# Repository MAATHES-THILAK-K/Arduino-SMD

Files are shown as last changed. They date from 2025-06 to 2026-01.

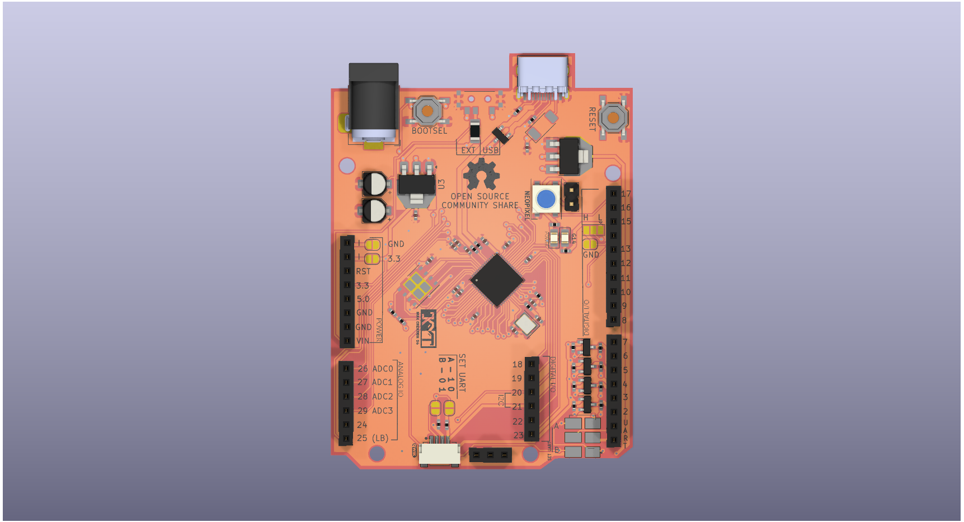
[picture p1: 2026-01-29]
OPENSOURCE_REMAKE/IMAGES/FRONT.png

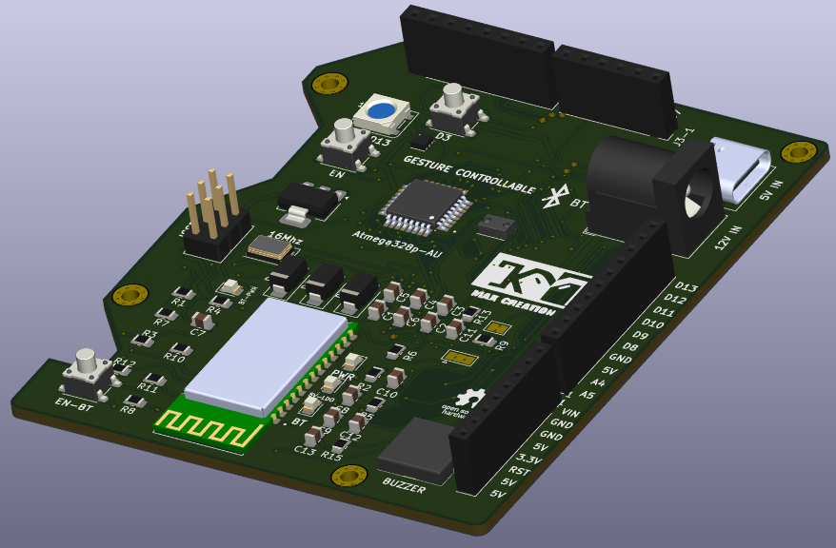
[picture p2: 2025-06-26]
ISOMETRIC_VIEW.png

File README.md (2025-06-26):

# Arduino-SMD

GrabCAD Link: [https://grabcad.com/library/arduino-smd-1](https://grabcad.com/library/arduino-smd-1)

This project is a compact, stylish, Arduino-compatible development board based on the **ATmega328P-AU** (TQFP). It includes several integrated peripherals making it ideal for wearable or IoT projects.

---

## 📦 Components

| Component | Description |
| --- | --- |
| **ATmega328P-AU** | 8-bit microcontroller (TQFP) |
| **AMS1117-3.3V LDO** | 5V to 3.3V regulator for APDS9960 & HC-05 |
| **TLV76750** | 12V to 5V LDO |
| **WS2812B** | RGB LED (Smart addressable) |
| **APDS-9960** | Gesture sensor (I2C) |
| **HC-05** | Bluetooth module |
| **Tactile Switch** | User input |
| **Active Buzzer** | Sound feedback |
| **USB-C (Power-only)** | 5V input only (no data lines) |
| **12V Barrel Jack** | Additional power input |
| **ICSP Header (2x3)** | For firmware flashing |
| **GPIO Headers** | Female headers for D0-D13, A0-A5 |
| **Various SMD Resistors & Capacitors** | For pull-ups, bypassing, filtering |

---

## ⚠️ Warning

> **The DRC (Design Rule Check) in KiCad was not fully resolved during initial layout. There may be trace width, clearance, or connectivity issues. Please verify the layout manually or run a complete DRC pass before fabrication.**

---

## 📁 Folder Info

* **Gerber/** → Ready-to-export Gerber files for fabrication
* **KiCad\_Project/** → All source files for the schematic & layout
* **images/** → (Optional) Screenshots, 3D renders of the board
* **LICENSE** → MIT License for reuse
* **.gitignore** → Standard for KiCad projects

---

## 🛠️ To-Do

* [ ] Fix all DRC errors
* [ ] Add 3D renders
* [ ] Test hardware once fabricated

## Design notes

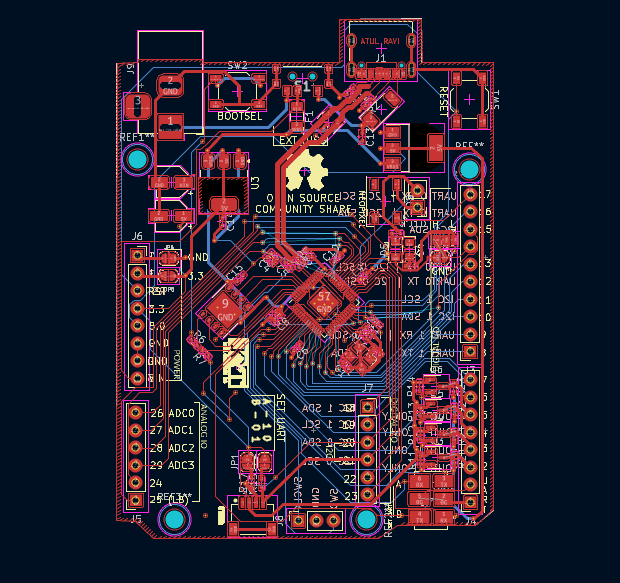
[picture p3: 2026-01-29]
OPENSOURCE_REMAKE/IMAGES/Screenshot from 2026-01-29 20-04-23.png

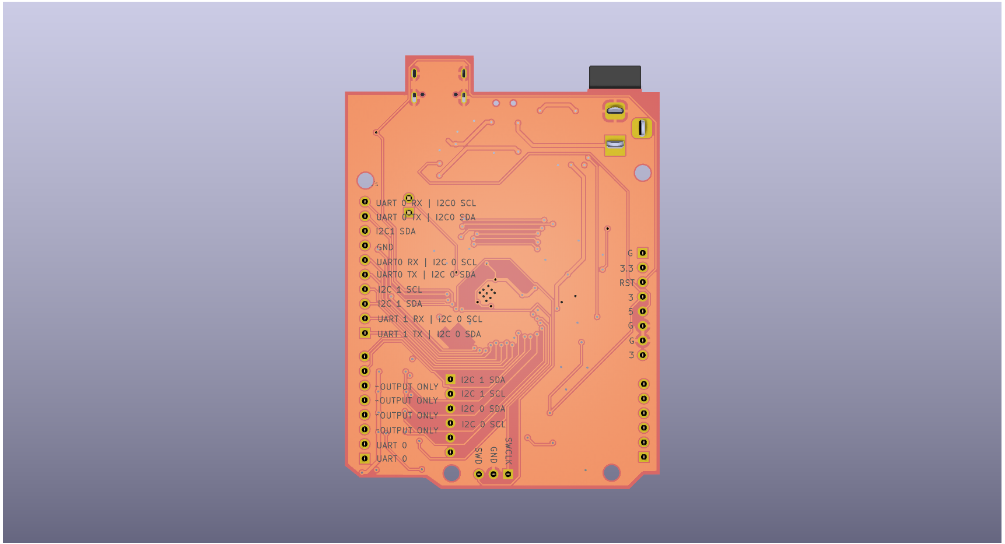
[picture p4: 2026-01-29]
OPENSOURCE_REMAKE/IMAGES/BACK.png

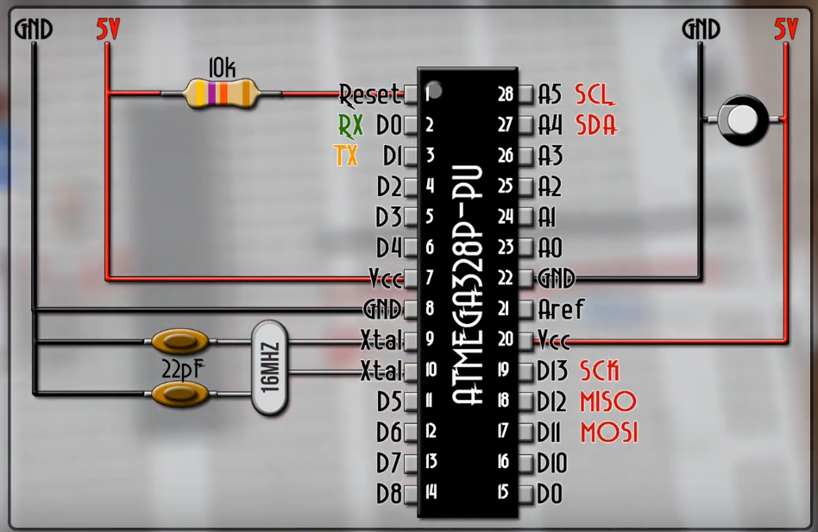
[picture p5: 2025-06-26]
BARE_MINIMUM_CONFIGURATION.png

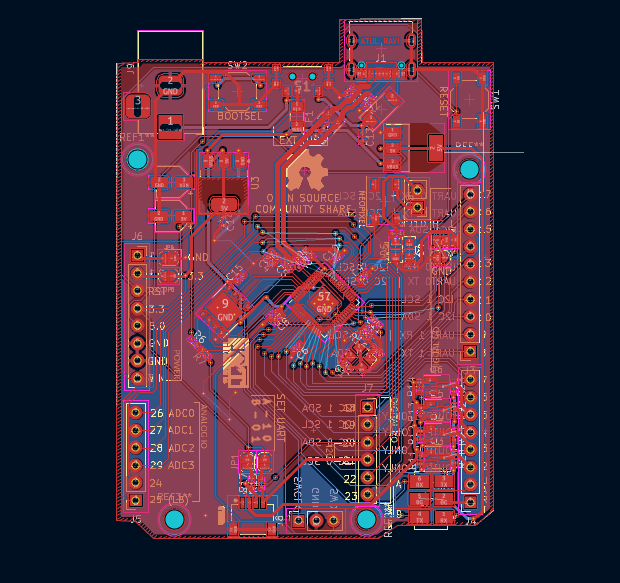
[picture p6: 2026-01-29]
OPENSOURCE_REMAKE/IMAGES/Screenshot from 2026-01-29 20-04-18.png

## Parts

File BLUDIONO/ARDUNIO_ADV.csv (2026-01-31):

Reference | Qty | Value | DNP | Exclude from BOM | Exclude from Board | Footprint | Datasheet
BZ1 | 1 | Buzzer |  |  |  | PKMCS0909E4000-R1:SPKR_PKMCS0909E4000-R1 | ~
C1,C2,C13 | 3 | 100nf |  |  |  | Capacitor_SMD:C_0805_2012Metric | ~
C3,C4 | 2 | 22pf |  |  |  | Capacitor_SMD:C_0805_2012Metric | ~
C5 | 1 | 1uf |  |  |  | Capacitor_SMD:C_0805_2012Metric | ~
C6 | 1 | 2.2uf |  |  |  | Capacitor_SMD:C_0805_2012Metric | ~
C7,C8 | 2 | 10uf |  |  |  | Capacitor_SMD:C_0805_2012Metric | ~
C9 | 1 | 0.1uf |  |  |  | Capacitor_SMD:C_0805_2012Metric | ~
C10 | 1 | 1.0uf |  |  |  | Capacitor_SMD:C_0805_2012Metric | ~
C11 | 1 | 100uf |  |  |  | Capacitor_SMD:C_0805_2012Metric | ~
C12 | 1 | 1.0fu |  |  |  | Capacitor_SMD:C_0805_2012Metric | ~
D1,D3,D5 | 3 | SS14 |  |  |  | Diode_SMD:D_SMA | https://www.vishay.com/docs/88746/ss12.pdf
D2,D6,D7,D8 | 4 | LED |  |  |  | LED_SMD:LED_0805_2012Metric | ~
D4 | 1 | WS2812B |  |  |  | LED_SMD:LED_WS2812B_PLCC4_5.0x5.0mm_P3.2mm | https://cdn-shop.adafruit.com/datasheets/WS2812B.pdf
H1,H2,H3,H4 | 4 | MountingHole |  | Excluded from BOM |  | MountingHole:MountingHole_2.2mm_M2_Pad_Via | ~
J1 | 1 | ICSP |  |  |  | Connector_PinHeader_2.54mm:PinHeader_2x03_P2.54mm_Vertical | ~
J1-1 | 1 | Conn_01x10_Pin |  |  |  | Connector_PinSocket_2.54mm:PinSocket_1x10_P2.54mm_Vertical | ~
J2 | 1 | USB_C_Receptacle_PowerOnly_6P |  |  |  | Connector_USB:USB_C_Receptacle_HRO_TYPE-C-31-M-12 | https://www.usb.org/sites/default/files/documents/usb_type-c.zip
J2-1,J4-1 | 2 | Conn_01x08_Pin |  |  |  | Connector_PinSocket_2.54mm:PinSocket_1x08_P2.54mm_Vertical | ~
J3 | 1 | Barrel_Jack |  |  |  | Connector_BarrelJack:BarrelJack_CUI_PJ-102AH_Horizontal | ~
J3-1 | 1 | Conn_01x06_Pin |  |  |  | Connector_PinSocket_2.54mm:PinSocket_1x06_P2.54mm_Vertical | ~
JP1 | 1 | SolderJumper_3_Bridged123 |  | Excluded from BOM |  | Jumper:SolderJumper-3_P1.3mm_Bridged2Bar123_Pad1.0x1.5mm | ~
JP2 | 1 | SolderJumper_2_Bridged |  | Excluded from BOM |  | Jumper:SolderJumper-2_P1.3mm_Bridged_Pad1.0x1.5mm | ~
R1,R7,R11 | 3 | 10k |  |  |  | Resistor_SMD:R_0805_2012Metric | ~
R2,R12 | 2 | 1k |  |  |  | Resistor_SMD:R_0805_2012Metric | ~
R3 | 1 | 330 |  |  |  | Resistor_SMD:R_0805_2012Metric | ~
R4 | 1 | 2.2k |  |  |  | Resistor_SMD:R_0805_2012Metric | ~
R5,R6 | 2 | 4.7k |  |  |  | Resistor_SMD:R_0805_2012Metric | ~
R8 | 1 | 100 |  |  |  | Resistor_SMD:R_0805_2012Metric | ~
R9 | 1 | DNP |  |  |  | Resistor_SMD:R_0805_2012Metric | ~
R10 | 1 | 2k |  |  |  | Resistor_SMD:R_0805_2012Metric | ~
R13,R14 | 2 | 5.1k |  |  |  | Resistor_SMD:R_0805_2012Metric | ~
R15 | 1 | 1M |  |  |  | Resistor_SMD:R_0805_2012Metric | ~
SW2,SW3,SW4 | 3 | SW_DPST_x2 |  |  |  | Button_Switch_SMD:SW_SPST_PTS647_Sx50 | ~
U1 | 1 | ATMEGA328P-AU |  |  |  | ATMEGA328P_AU:QFP80P900X900X120-32N
U2 | 1 | TLV76750DRVx |  |  |  | Package_SON:WSON-6-1EP_2x2mm_P0.65mm_EP1x1.6mm_ThermalVias | www.ti.com/lit/gpn/TLV767
U3 | 1 | AMS1117-3.3 |  |  |  | Package_TO_SOT_SMD:SOT-223-3_TabPin2 | http://www.advanced-monolithic.com/pdf/ds1117.pdf
U4 | 1 | APDS-9960 |  |  |  | Sensor:Avago_APDS-9960 | https://docs.broadcom.com/doc/AV02-4191EN
U5 | 1 | HC-05 |  |  |  | HC-05:XCVR_HC-05
Y1 | 1 | Crystal |  |  |  | Crystal:Crystal_SMD_5032-2Pin_5.0x3.2mm | ~

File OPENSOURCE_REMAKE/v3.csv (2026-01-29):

Reference | Qty | Value | DNP | Exclude from BOM | Exclude from Board | Footprint | Datasheet
C1,C2 | 2 | 27p |  |  |  | Capacitor_SMD:C_0402_1005Metric_Pad0.74x0.62mm_HandSolder | ~
C3,C4,C6,C7,C8,C9,C10,C11,C15 | 9 | 100n |  |  |  | Capacitor_SMD:C_0402_1005Metric_Pad0.74x0.62mm_HandSolder | ~
C5,C12 | 2 | 1u |  |  |  | Capacitor_SMD:C_0402_1005Metric_Pad0.74x0.62mm_HandSolder | ~
C13 | 1 | 10u |  |  |  | Capacitor_SMD:C_0402_1005Metric_Pad0.74x0.62mm_HandSolder | ~
C14 | 1 | 22pF |  |  |  | Capacitor_SMD:C_0402_1005Metric_Pad0.74x0.62mm_HandSolder | ~
C16,C17 | 2 | 10uF |  |  |  | Capacitor_SMD:CP_Elec_4x5.4 | ~
D1 | 1 | D_Schottky |  |  |  | Diode_SMD:D_SOD-128 | ~
D2 | 1 | WS2812B |  |  |  | LED_SMD:LED_WS2812B_PLCC4_5.0x5.0mm_P3.2mm | https://cdn-shop.adafruit.com/datasheets/WS2812B.pdf
D3 | 1 | D_TVS_Dual_AAC |  |  |  | Package_TO_SOT_SMD:SOT-23 | ~
D4,D5 | 2 | LED |  |  |  | LED_SMD:LED_0805_2012Metric_Pad1.15x1.40mm_HandSolder | ~
F1 | 1 | Fuse |  |  |  | Fuse:Fuse_1206_3216Metric_Pad1.42x1.75mm_HandSolder | ~
J1 | 1 | USB_C_Receptacle_USB2.0 |  |  |  | Connector_USB:USB_C_Receptacle_G-Switch_GT-USB-7010ASV | https://www.usb.org/sites/default/files/documents/usb_type-c.zip
J2 | 1 | SM04B-SRSS-TB_LF__SN_ |  |  |  | SPARKFUN-QWIIC:JST_SM04B-SRSS-TB_LF__SN_
J3 | 1 | Conn_01x10_Socket |  |  |  | Connector_PinSocket_2.54mm:PinSocket_1x10_P2.54mm_Vertical | ~
J4,J6 | 2 | Conn_01x08_Socket |  |  |  | Connector_PinSocket_2.54mm:PinSocket_1x08_P2.54mm_Vertical | ~
J5 | 1 | Conn_01x06_Pin |  |  |  | Connector_PinSocket_2.54mm:PinSocket_1x06_P2.54mm_Vertical | ~
J7 | 1 | Conn_01x06_Socket |  |  |  | Connector_PinSocket_2.54mm:PinSocket_1x06_P2.54mm_Vertical | ~
J8 | 1 | Conn_01x03_Pin |  |  |  | Connector_PinSocket_2.54mm:PinSocket_1x03_P2.54mm_Vertical | ~
J9 | 1 | Barrel_Jack_Switch |  |  |  | Connector_BarrelJack:BarrelJack_Horizontal | ~
J10 | 1 | Conn_01x02_Pin |  |  |  | Connector_PinHeader_2.54mm:PinHeader_1x02_P2.54mm_Vertical | ~
JP1,JP2,JP7,JP8 | 4 | Jumper_2_Bridged |  |  |  | Jumper:SolderJumper-2_P1.3mm_Open_RoundedPad1.0x1.5mm | ~
JP3 | 1 | Jumper_3_Open |  |  |  | Jumper:SolderJumper-3_P1.3mm_Open_Pad1.0x1.5mm | ~
JP4 | 1 | Jumper_2_Open |  |  |  | Jumper:SolderJumper-2_P1.3mm_Open_RoundedPad1.0x1.5mm | ~
Q3,Q4,Q5,Q6 | 4 | BSS138 |  |  |  | Package_TO_SOT_SMD:SOT-23 | https://www.onsemi.com/pub/Collateral/BSS138-D.PDF
R1,R8 | 2 | 220 |  |  |  | Resistor_SMD:R_0402_1005Metric_Pad0.72x0.64mm_HandSolder | ~
R2,R3,R33 | 3 | 5.1K |  |  |  | Resistor_SMD:R_0402_1005Metric_Pad0.72x0.64mm_HandSolder | ~
R4,R5 | 2 | 27R |  |  |  | Resistor_SMD:R_0402_1005Metric_Pad0.72x0.64mm_HandSolder | ~
R6,R16 | 2 | 1k |  |  |  | Resistor_SMD:R_0402_1005Metric_Pad0.72x0.64mm_HandSolder | ~
R7 | 1 | 10k |  |  |  | Resistor_SMD:R_0402_1005Metric_Pad0.72x0.64mm_HandSolder | ~
R11,R12,R13,R14,R20,R21,R22,R23 | 8 | 10K |  |  |  | Resistor_SMD:R_0402_1005Metric_Pad0.72x0.64mm_HandSolder | ~
R15,R17 | 2 | 2.2K |  |  |  | Resistor_SMD:R_0402_1005Metric_Pad0.72x0.64mm_HandSolder | ~
S1 | 1 | SK-3296S-01-L3 |  |  |  | switchess:SK3296S01L3 | https://datasheet.lcsc.com/szlcsc/XKB-SK-3296S-01-L3_C319019.pdf
SW1 | 1 | TACT SW |  |  |  | Button_Switch_SMD:SW_SPST_TL3342 | PTS526SP20SMTR2 LFS
SW2 | 1 | 4*4*1/5 SMD tact SW |  |  |  | Button_Switch_SMD:SW_SPST_TL3342 | https://www.ktron.in/product/4x4x1-5mm-smd-tactile-switch/
SW3 | 1 | SW_DPDT_x2 |  |  |  | switchess:SW_CL-SB-22A-02T | SMMD
U1 | 1 | RP2040 |  |  |  | Package_DFN_QFN:QFN-56-1EP_7x7mm_P0.4mm_EP3.2x3.2mm | https://datasheets.raspberrypi.com/rp2040/rp2040-datasheet.pdf
U3 | 1 | AMS1117-3.3 |  |  |  | Package_TO_SOT_SMD:SOT-223-3_TabPin2 | http://www.advanced-monolithic.com/pdf/ds1117.pdf
U4 | 1 | AMS1117-5.0 |  |  |  | Package_TO_SOT_SMD:SOT-223-3_TabPin2 | http://www.advanced-monolithic.com/pdf/ds1117.pdf
U5 | 1 | W25Q32JVZP |  |  |  | Package_SON:WSON-8-1EP_6x5mm_P1.27mm_EP3.4x4.3mm | http://www.winbond.com/resource-files/w25q32jv%20revg%2003272018%20plus.pdf
Y1 | 1 | \YSX321SL 12 Mhz |  |  |  | Crystal:Crystal_SMD_3225-4Pin_3.2x2.5mm | https://www.ktron.in/wp-content/uploads/2023/02/YSX321SL-Datasheet.pdf

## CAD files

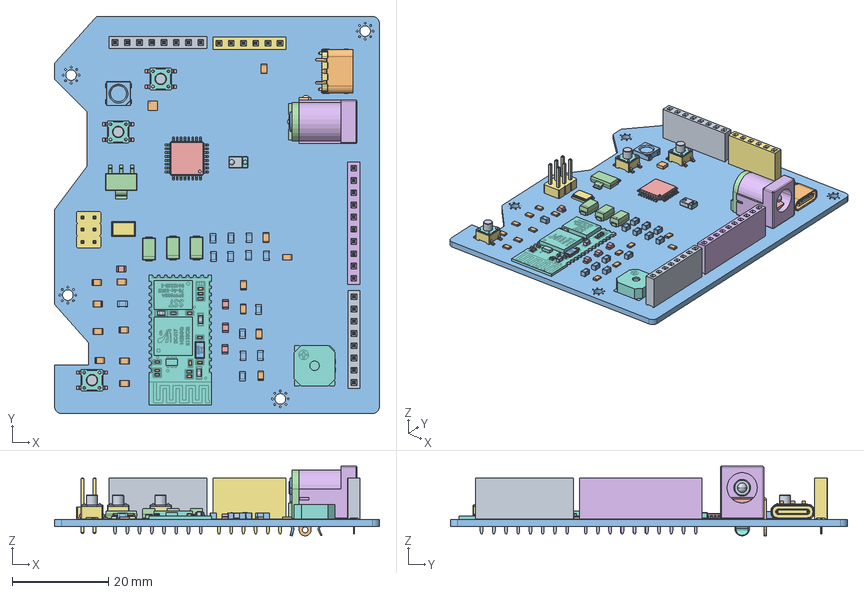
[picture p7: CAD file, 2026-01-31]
BLUDIONO/3D MODEL/ARDUNIO_ADV.step
67.5 x 82.5 x 14.5 mm
R_0805_2012Metric x 15
C_0805_2012Metric x 13
D_SMA x 3
SW_SPST_PTS647Sx50 x 3
USB-C
DCJ200-10-A-K1-K--3DModel-STEP-56544
PinSocket_1x06_P2.54mm_Vertical
smd_buzz
PinSocket_1x08_P2.54mm_Vertical x 2
WSON-6-1EP_2x2mm_P0.65mm_EP1x1.6mm
LED_WS2812B_PLCC4_5.0x5.0mm_P3.2mm
SOT-223
LED_0805_2012Metric x 4
PinSocket_1x10_P2.54mm_Vertical
Crystal_SMD_5032-2Pin_5.0x3.2mm
HC05_06
C0603 x 3
R0402 x 4
C0402 x 9
QSMD7.0x5.0x1.3
ATMEGA328P-AU
PinHeader_2x03_P2.54mm_Vertical
APDS-9960
ARDUNIO_ADV_PCB

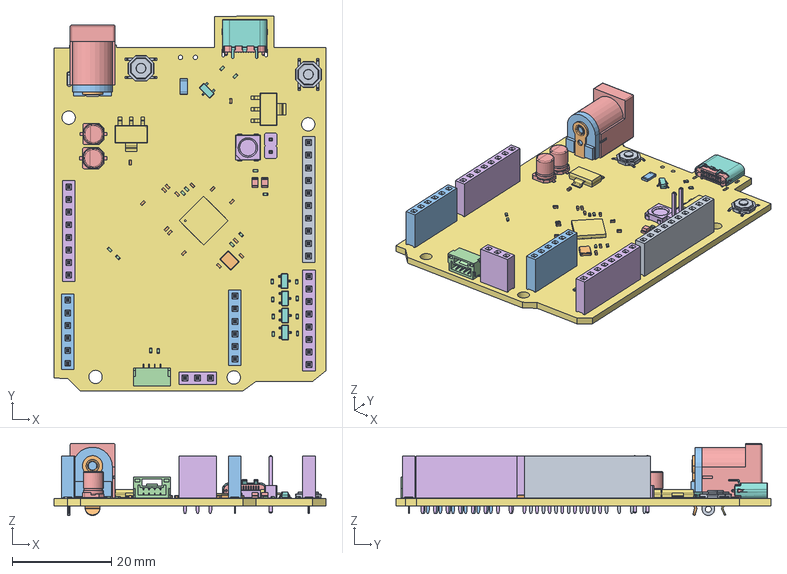
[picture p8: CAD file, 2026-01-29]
OPENSOURCE_REMAKE/3D MODEL/capacitive-midi-pad1.step
54.8 x 75.5 x 14.5 mm
SW_SPST_TL3342 x 2
C_0402_1005Metric x 15
PinSocket_1x06_P2.54mm_Vertical x 2
R_0402_1005Metric x 20
CP_Elec_4x5.4 x 2
PinSocket_1x08_P2.54mm_Vertical x 2
SOT-223 x 2
SOT-23 x 5
PinSocket_1x10_P2.54mm_Vertical
Crystal_SMD_3225-4Pin_3.2x2.5mm
Fuse_1206_3216Metric
JST_GH_SM04B-GHS-TB_1x04-1MP_P1.25mm_Horizontal
LED_0805_2012Metric x 2
PinHeader_1x02_P2.54mm_Vertical
QFN-56-1EP_7x7mm_P0.4mm_EP3.2x3.2mm
USB-C
LED_WS2812B_PLCC4_5.0x5.0mm_P3.2mm
DCJ200-10-A-K1-K--3DModel-STEP-56544
PinSocket_1x03_P2.54mm_Vertical
v3_PCB

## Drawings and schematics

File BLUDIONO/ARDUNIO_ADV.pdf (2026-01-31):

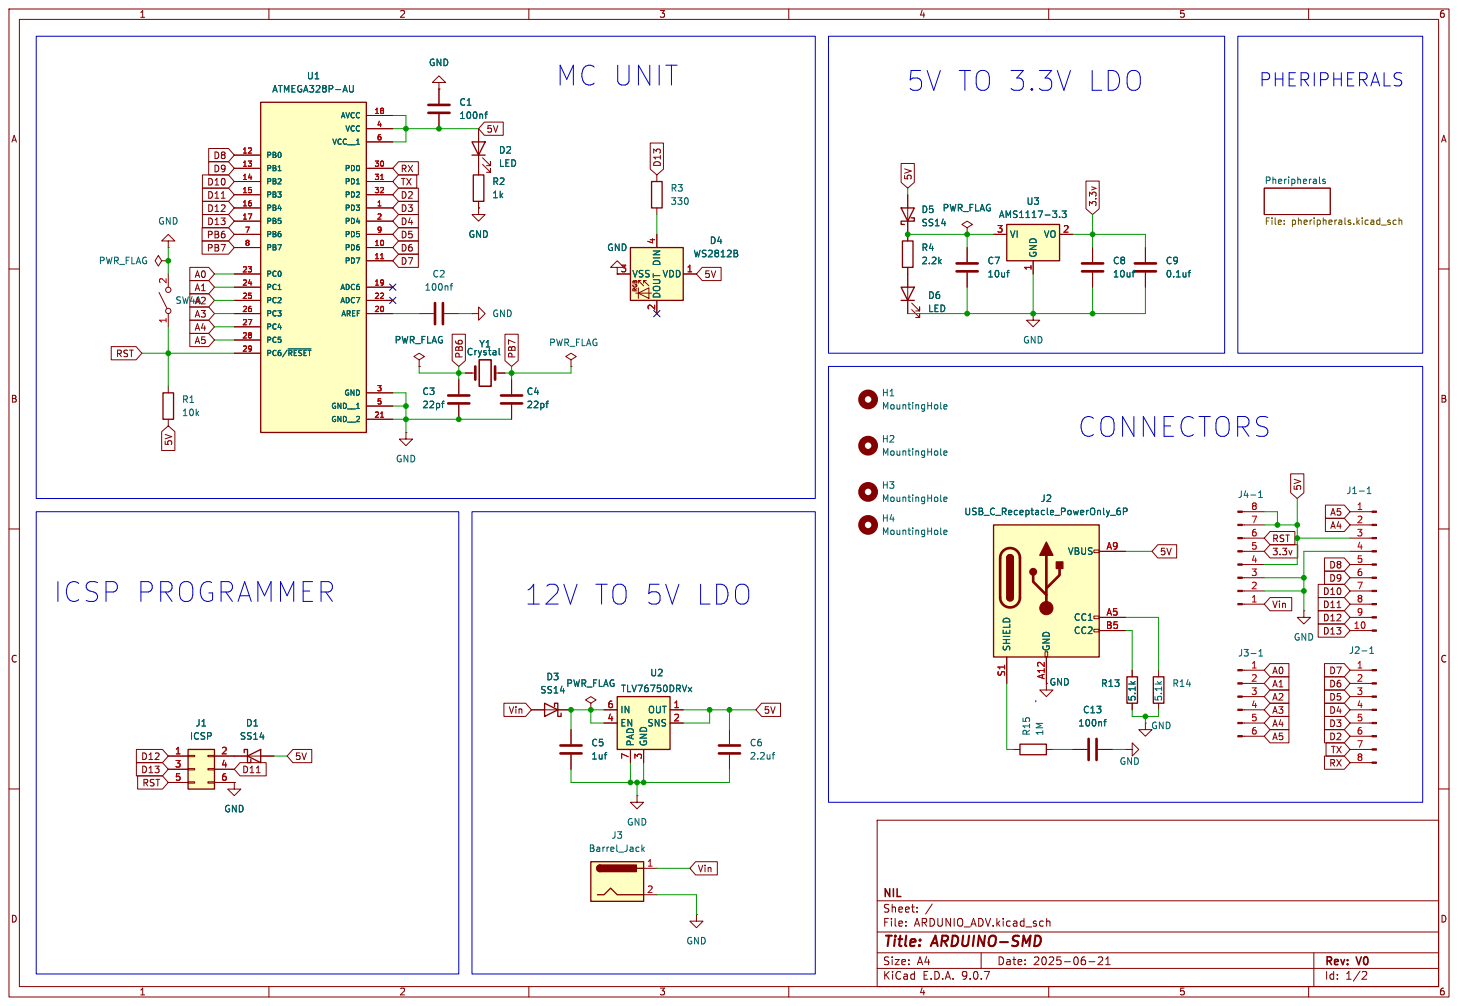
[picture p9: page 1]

Pheripherals File: pheripherals.kicad_sch GND

Id: 1/2 Title: ARDUINO-SMD

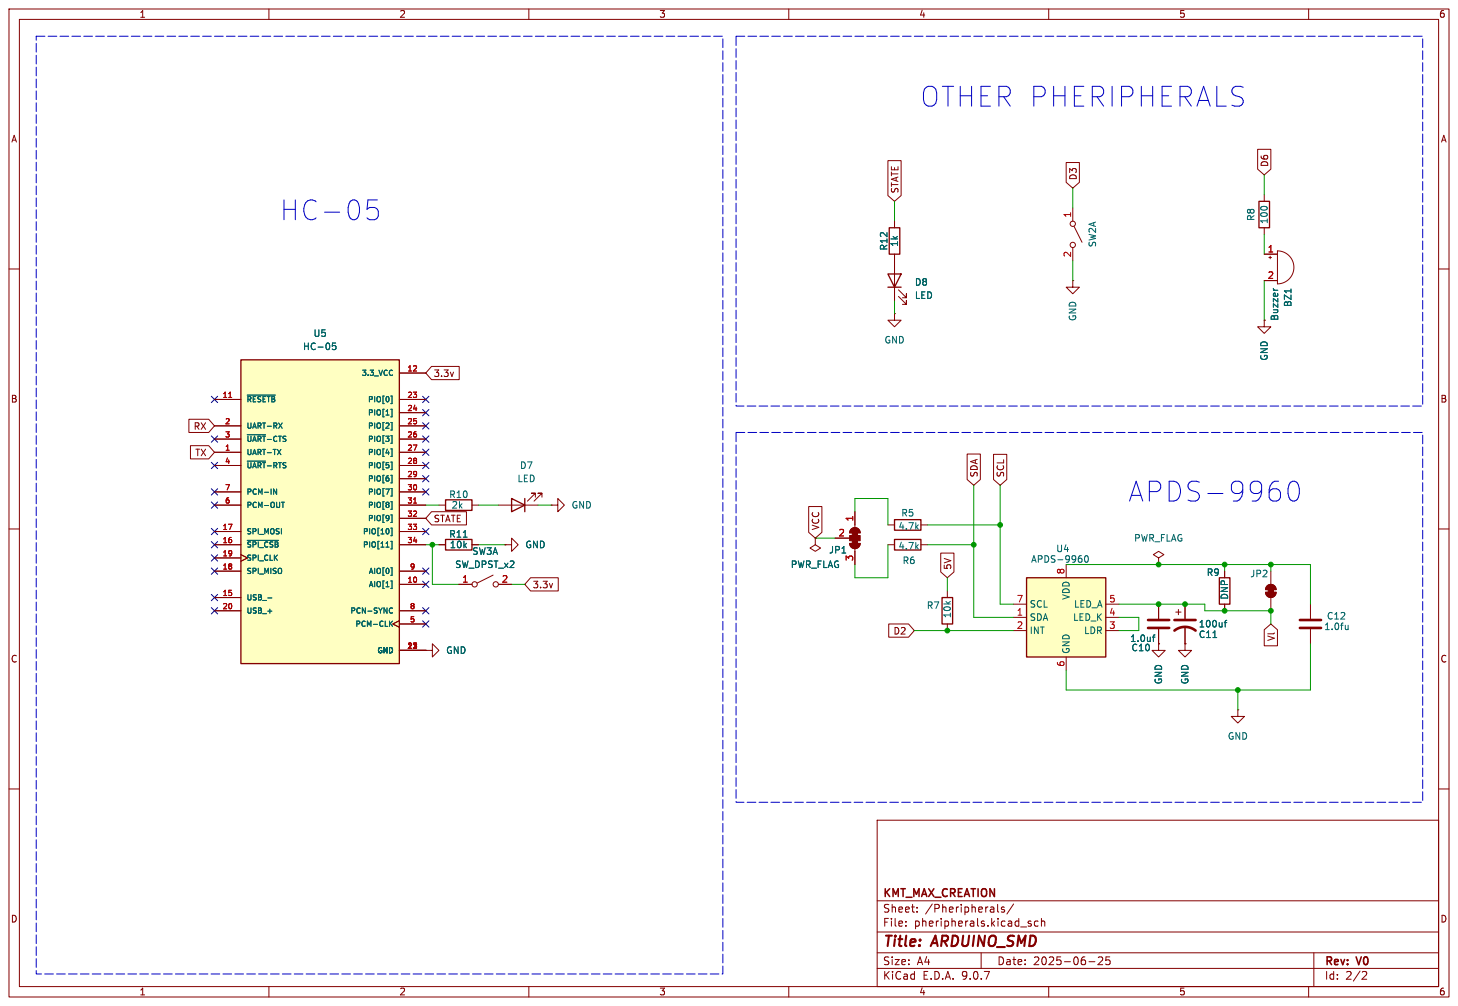
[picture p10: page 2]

KMT_MAX_CREATION
File: pheripherals.kicad_sch Sheet: /Pheripherals/
Id: 2/2 Title: ARDUINO_SMD

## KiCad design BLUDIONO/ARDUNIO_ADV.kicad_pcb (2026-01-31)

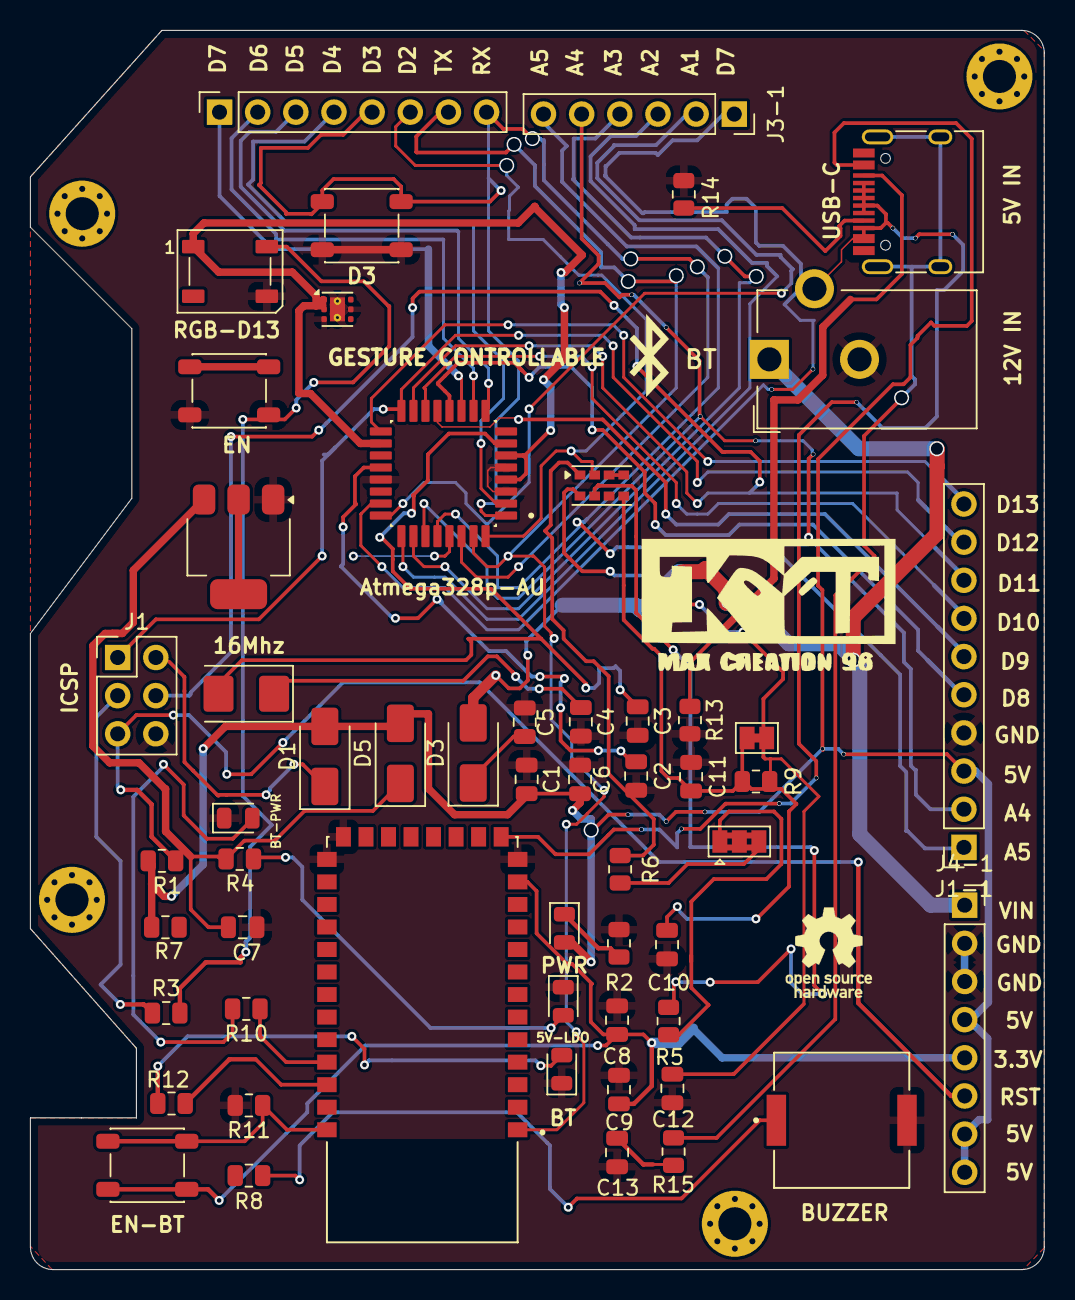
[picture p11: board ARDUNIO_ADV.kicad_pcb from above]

Board: 2 copper layers, 67.5 x 82.5 mm, 59 parts (0 on the bottom side), 51 nets.

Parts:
5V-LDO: LED; LED_0805_2012Metric
12V IN: Barrel_Jack; BarrelJack_CUI_PJ-102AH_Horizontal
16Mhz: Crystal; Crystal_SMD_5032-2Pin_5.0x3.2mm
BT: LED; LED_0805_2012Metric
BT-PWR: LED; LED_0805_2012Metric
BZ1: Buzzer; SPKR_PKMCS0909E4000-R1
C1, C2, C13: 100nf; C_0805_2012Metric
C3, C4: 22pf; C_0805_2012Metric
C5: 1uf; C_0805_2012Metric
C6: 2.2uf; C_0805_2012Metric
C7, C8: 10uf; C_0805_2012Metric
C9: 0.1uf; C_0805_2012Metric
C10: 1.0uf; C_0805_2012Metric
C11: 100uf; C_0805_2012Metric
C12: 1.0fu; C_0805_2012Metric
D1, D3#2, D5: SS14; D_SMA
D3: SW_DPST_x2; SW_SPST_PTS647_Sx50
EN: SW_DPST_x2; SW_SPST_PTS647_Sx50
EN-BT: SW_DPST_x2; SW_SPST_PTS647_Sx50
H1, H2, H3, H4: MountingHole; MountingHole_2.2mm_M2_Pad_Via
J1: ICSP; PinHeader_2x03_P2.54mm_Vertical
J1-1: Conn_01x10_Pin; PinSocket_1x10_P2.54mm_Vertical
J2-1, J4-1: Conn_01x08_Pin; PinSocket_1x08_P2.54mm_Vertical
J3-1: Conn_01x06_Pin; PinSocket_1x06_P2.54mm_Vertical
JP1: SolderJumper_3_Bridged123; SolderJumper-3_P1.3mm_Bridged2Bar123_Pad1.0x1.5mm
JP2: SolderJumper_2_Bridged; SolderJumper-2_P1.3mm_Bridged_Pad1.0x1.5mm
PWR: LED; LED_0805_2012Metric
R1, R7, R11: 10k; R_0805_2012Metric
R2, R12: 1k; R_0805_2012Metric
R3: 330; R_0805_2012Metric
R4: 2.2k; R_0805_2012Metric
R5, R6: 4.7k; R_0805_2012Metric
R8: 100; R_0805_2012Metric
R9: DNP; R_0805_2012Metric
R10: 2k; R_0805_2012Metric
R13, R14: 5.1k; R_0805_2012Metric
R15: 1M; R_0805_2012Metric
RGB-D13: WS2812B; LED_WS2812B_PLCC4_5.0x5.0mm_P3.2mm
U1: ATMEGA328P-AU; QFP80P900X900X120-32N
U2: TLV76750DRVx; WSON-6-1EP_2x2mm_P0.65mm_EP1x1.6mm_ThermalVias
U3: AMS1117-3.3; SOT-223-3_TabPin2
U4: APDS-9960; Avago_APDS-9960
U5: HC-05; XCVR_HC-05
USB-C: USB_C_Receptacle_PowerOnly_6P; USB_C_Receptacle_HRO_TYPE-C-31-M-12

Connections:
3.3v: C8.1, C9.1, EN-BT.2 (B), J4-1.5, U3.2 (VO), U5.12 (3.3_VCC)
5V: C1.2, C6.1, D1.2 (A), D5.2 (A), J1-1.3, J4-1.4, J4-1.7, J4-1.8, PWR.2 (A), R1.2, R7.1, RGB-D13.1 (VDD), U1.4 (VCC), U1.6 (VCC__1), U1.18 (AVCC), U2.1 (OUT), U2.2 (SNS), USB-C.A9 (VBUS), USB-C.B9 (VBUS)
A0: J3-1.1, U1.23 (PC0)
A1: J3-1.2, U1.24 (PC1)
A2: J3-1.3, U1.25 (PC2)
A3: J3-1.4, U1.26 (PC3)
A4: J1-1.2, J3-1.5, U1.27 (PC4)
A5: J1-1.1, J3-1.6, U1.28 (PC5)
D2: J2-1.6, R7.2, U1.32 (PD2), U4.2 (INT)
D3: D3.1 (A), J2-1.5, U1.1 (PD3)
D4: J2-1.4, U1.2 (PD4)
D5: J2-1.3, U1.9 (PD5)
D6: J2-1.2, R8.1, U1.10 (PD6)
D7: J2-1.1, U1.11 (PD7)
D8: J1-1.5, U1.12 (PB0)
D9: J1-1.6, U1.13 (PB1)
D10: J1-1.7, U1.14 (PB2)
D11: J1.4, J1-1.8, U1.15 (PB3)
D12: J1.1, J1-1.9, U1.16 (PB4)
D13: J1.3, J1-1.10, R3.1, U1.17 (PB5)
GND: 5V-LDO.1 (K), 12V IN.2, BT.1 (K), BT-PWR.1 (K), BZ1.2 (-), C1.1, C2.2, C3.2, C4.2, C5.2, C6.2, C7.2, C8.2, C9.2, C10.1, C11.2, C12.2, C13.2, D3.2 (B), EN.2 (B), J1.6, J1-1.4, J4-1.2, J4-1.3, R2.1, R11.2, R13.2, R14.2, RGB-D13.3 (VSS), U1.3 (GND), U1.5 (GND__1), U1.21 (GND__2), U2.3 (GND), U2.5 (GND), U2.7 (PAD), U3.1 (GND), U4.6 (GND), U5.13 (GND), U5.21 (GND), U5.22 (GND), USB-C.A12 (GND), USB-C.B12 (GND)
unnamed: BZ1.1 (+), R8.2
unnamed: C13.1, R15.2
unnamed: D1.1 (K), J1.2
unnamed: PWR.1 (K), R2.2
unnamed: C5.1, D3#2.1 (K), U2.4 (EN), U2.6 (IN)
unnamed: R3.2, RGB-D13.4 (DIN)
unnamed: C7.1, D5.1 (K), R4.1, U3.3 (VI)
unnamed: 5V-LDO.2 (A), R4.2
unnamed: BT-PWR.2 (A), R10.2
unnamed: BT.2 (A), R12.1
unnamed: R14.1, USB-C.A5 (CC1)
unnamed: R13.1, USB-C.B5 (CC2)
unnamed: R15.1, USB-C.S1 (SHIELD)
unnamed: JP1.1 (A), R5.1
unnamed: JP1.3 (B), R6.1
unnamed: C12.1, JP2.2 (B), R9.1, U4.8 (VDD)
unnamed: EN-BT.1 (A), R11.1, U5.34 (PIO[11])
unnamed: C2.1, U1.20 (AREF)
unnamed: U4.3 (LDR), U4.4 (LED_K)
unnamed: R10.1, U5.31 (PIO[8])
PB6: 16Mhz.2, C3.1, U1.7 (PB6)
PB7: 16Mhz.1, C4.1, U1.8 (PB7)
RST: EN.1 (A), J1.5, J4-1.6, R1.1, U1.29 (PC6/~RESET)
RX: J2-1.8, U1.30 (PD0), U5.2 (UART-RX)
SCL: R5.2, U4.7 (SCL)
SDA: R6.2, U4.1 (SDA)
STATE: R12.2, U5.32 (PIO[9])
TX: J2-1.7, U1.31 (PD1), U5.1 (UART-TX)
Vin: 12V IN.1, D3#2.2 (A), J4-1.1
Vl: C10.2, C11.1, JP2.1 (A), R9.2, U4.5 (LED_A)

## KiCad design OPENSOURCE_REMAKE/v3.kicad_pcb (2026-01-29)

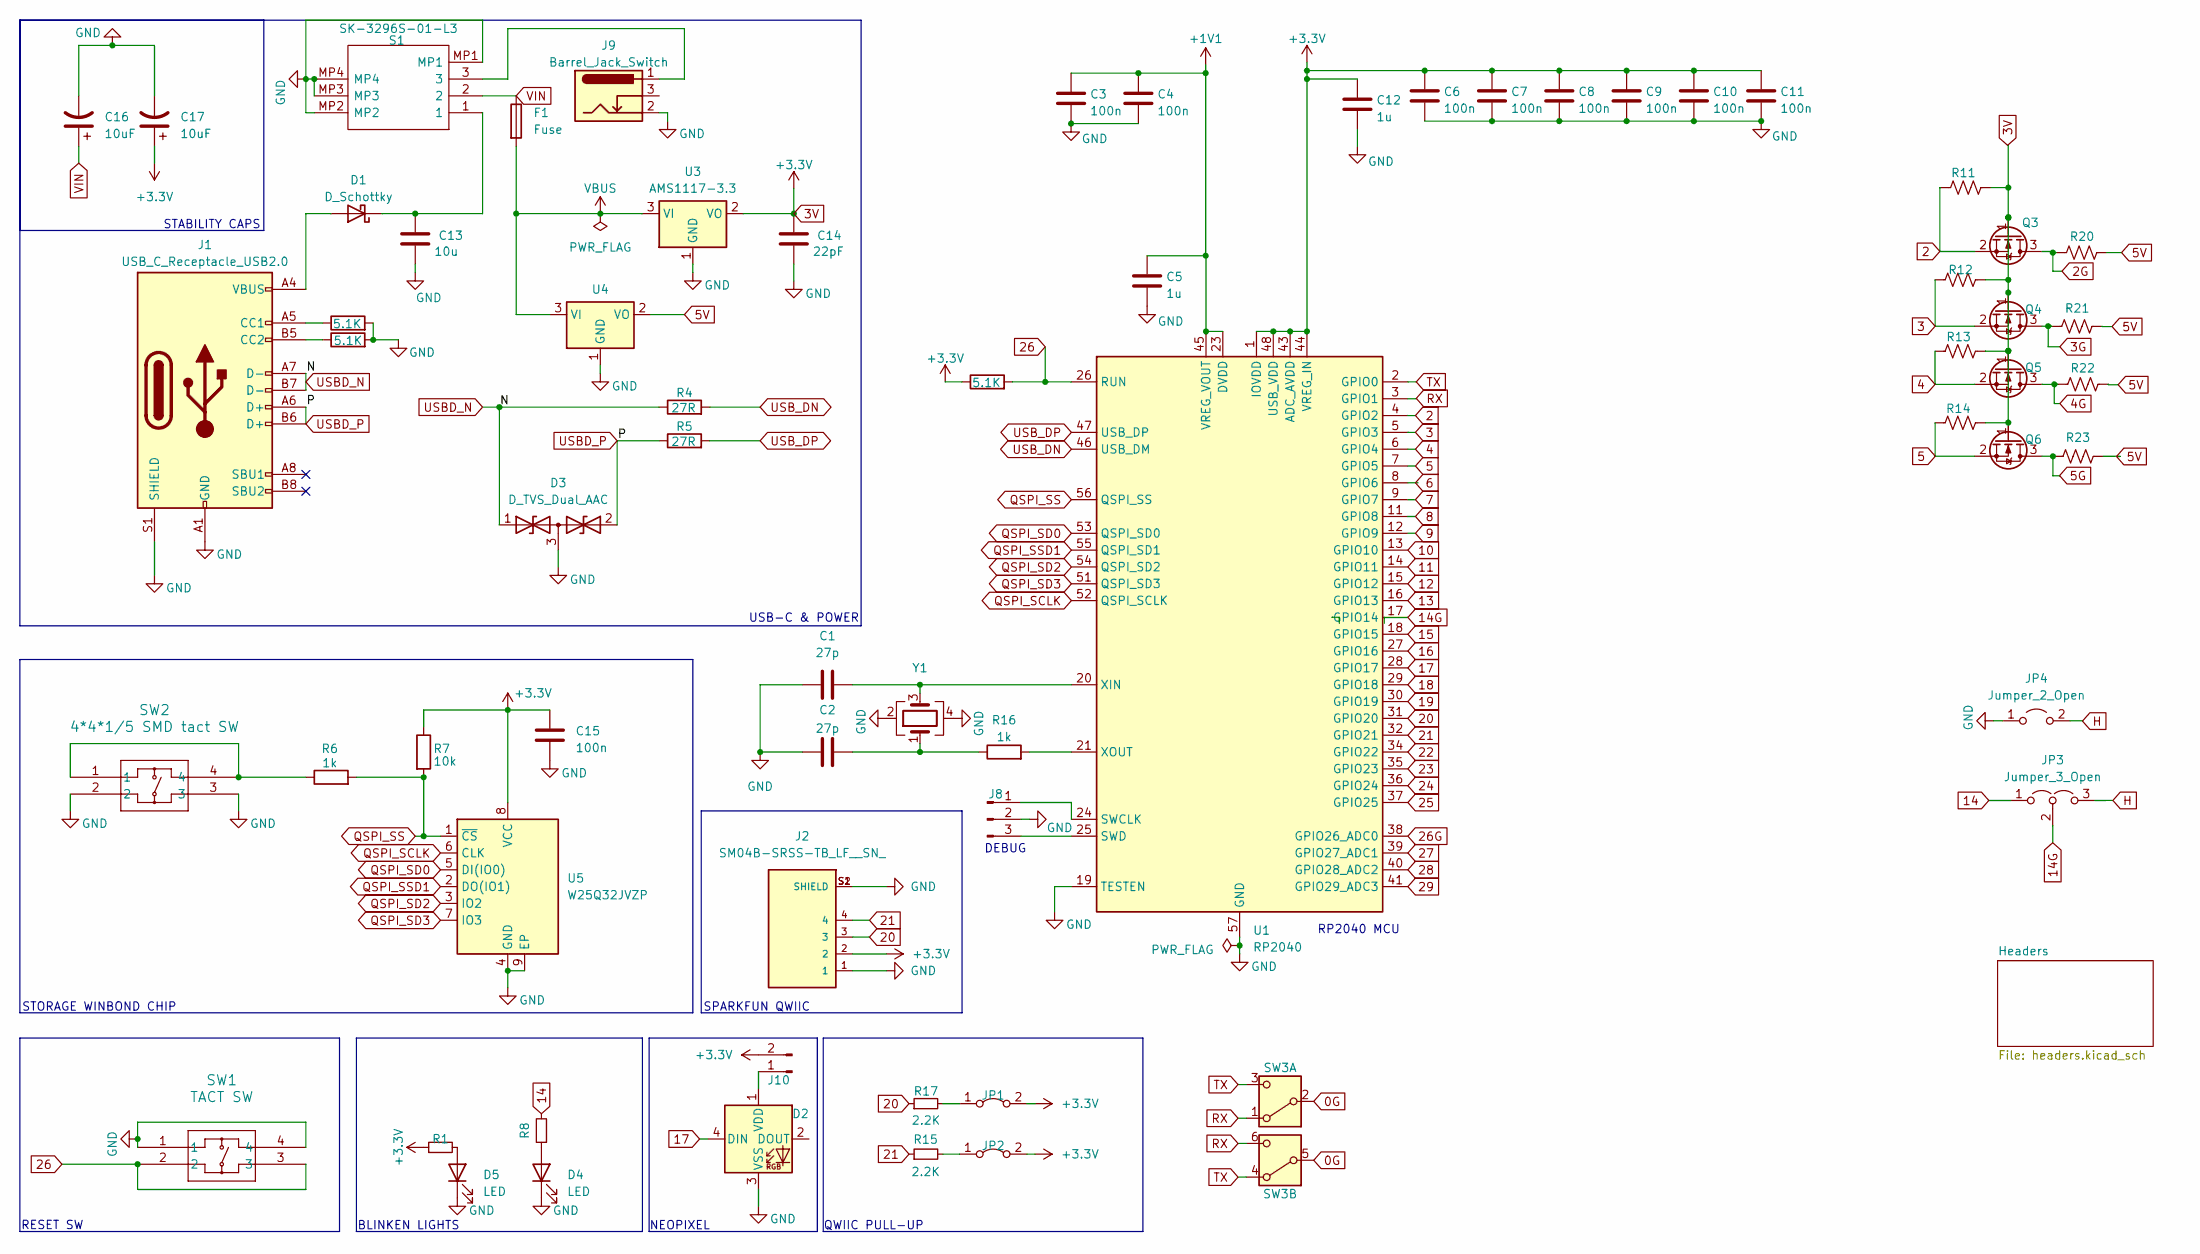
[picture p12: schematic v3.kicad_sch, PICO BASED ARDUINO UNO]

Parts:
C1, C2: 27p; C_0402_1005Metric_Pad0.74x0.62mm_HandSolder
C3, C4, C6, C7, C8, C9, C10, C11, C15: 100n; C_0402_1005Metric_Pad0.74x0.62mm_HandSolder
C5, C12: 1u; C_0402_1005Metric_Pad0.74x0.62mm_HandSolder
C13: 10u; C_0402_1005Metric_Pad0.74x0.62mm_HandSolder
C14: 22pF; C_0402_1005Metric_Pad0.74x0.62mm_HandSolder
C16, C17: 10uF; CP_Elec_4x5.4; LCSC C4747971
D1: D_Schottky; D_SOD-128
D2: WS2812B; LED_WS2812B_PLCC4_5.0x5.0mm_P3.2mm
D3: D_TVS_Dual_AAC; SOT-23
D4, D5: LED; LED_0805_2012Metric_Pad1.15x1.40mm_HandSolder
F1: Fuse; Fuse_1206_3216Metric_Pad1.42x1.75mm_HandSolder
J1: USB_C_Receptacle_USB2.0; USB_C_Receptacle_G-Switch_GT-USB-7010ASV
J2: SM04B-SRSS-TB_LF__SN_; JST_SM04B-SRSS-TB_LF__SN_
J8: Conn_01x03_Pin; PinSocket_1x03_P2.54mm_Vertical
J9: Barrel_Jack_Switch; BarrelJack_Horizontal
J10: Conn_01x02_Pin; PinHeader_1x02_P2.54mm_Vertical
JP1, JP2: Jumper_2_Bridged; SolderJumper-2_P1.3mm_Open_RoundedPad1.0x1.5mm
JP3: Jumper_3_Open; SolderJumper-3_P1.3mm_Open_Pad1.0x1.5mm
JP4: Jumper_2_Open; SolderJumper-2_P1.3mm_Open_RoundedPad1.0x1.5mm
Q3, Q4, Q5, Q6: BSS138; SOT-23
R1, R8: 220; R_0402_1005Metric_Pad0.72x0.64mm_HandSolder
R2, R3, R33: 5.1K; R_0402_1005Metric_Pad0.72x0.64mm_HandSolder
R4, R5: 27R; R_0402_1005Metric_Pad0.72x0.64mm_HandSolder
R6, R16: 1k; R_0402_1005Metric_Pad0.72x0.64mm_HandSolder
R7: 10k; R_0402_1005Metric_Pad0.72x0.64mm_HandSolder
R11, R12, R13, R14, R20, R21, R22, R23: 10K; R_0402_1005Metric_Pad0.72x0.64mm_HandSolder
R15, R17: 2.2K; R_0402_1005Metric_Pad0.72x0.64mm_HandSolder
S1: SK-3296S-01-L3; SK3296S01L3; Manufacturer_Part_Number SK-3296S-01-L3
SW1: TACT SW; SW_SPST_TL3342
SW2: 4*4*1/5 SMD tact SW; SW_SPST_TL3342
SW3: SW_DPDT_x2; SW_CL-SB-22A-02T; MFG Part No C2904912
U1: RP2040; QFN-56-1EP_7x7mm_P0.4mm_EP3.2x3.2mm
U3: AMS1117-3.3; SOT-223-3_TabPin2
U4: AMS1117-5.0; SOT-223-3_TabPin2
U5: W25Q32JVZP; WSON-8-1EP_6x5mm_P1.27mm_EP3.4x4.3mm
Y1: \YSX321SL 12 Mhz; Crystal_SMD_3225-4Pin_3.2x2.5mm

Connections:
0G: SW3.2 (B), SW3.5 (B)
2: Q3.2 (S), R11.1, U1.4 (GPIO2)
2G: Q3.3 (D), R20.1
3: Q4.2 (S), R12.1, U1.5 (GPIO3)
3G: Q4.3 (D), R21.1
3V: C6.1, C7.1, C8.1, C9.1, C10.1, C11.1, C12.1, C14.1, C15.1, C17.1, J2.2, J10.2, JP1.2 (B), JP2.2 (B), Q3.1 (G), Q4.1 (G), Q5.1 (G), Q6.1 (G), R1.1, R7.1, R11.2, R12.2, R13.2, R14.2, R33.1, U1.1 (IOVDD), U1.10 (IOVDD), U1.22 (IOVDD), U1.33 (IOVDD), U1.42 (IOVDD), U1.43 (ADC_AVDD), U1.44 (VREG_IN), U1.48 (USB_VDD), U1.49 (IOVDD), U3.2 (VO), U5.8 (VCC); also elsewhere on the board
4: Q5.2 (S), R13.1, U1.6 (GPIO4)
4G: Q5.3 (D), R22.1
5: Q6.2 (S), R14.1, U1.7 (GPIO5)
5G: Q6.3 (D), R23.1
5V: R20.2, R21.2, R22.2, R23.2, U4.2 (VO); also elsewhere on the board
6: U1.8 (GPIO6)
7: U1.9 (GPIO7)
8: U1.11 (GPIO8)
9: U1.12 (GPIO9)
10: U1.13 (GPIO10)
11: U1.14 (GPIO11)
12: U1.15 (GPIO12)
13: U1.16 (GPIO13)
14: JP3.1 (A), R8.2
14G: JP3.2 (C), U1.17 (GPIO14)
15: U1.18 (GPIO15)
16: U1.27 (GPIO16)
17: D2.4 (DIN), U1.28 (GPIO17); also elsewhere on the board
18: U1.29 (GPIO18)
19: U1.30 (GPIO19)
20: J2.3, R17.1, U1.31 (GPIO20); also elsewhere on the board
21: J2.4, R15.1, U1.32 (GPIO21); also elsewhere on the board
22: U1.34 (GPIO22)
23: U1.35 (GPIO23)
24: U1.36 (GPIO24); also elsewhere on the board
25: U1.37 (GPIO25); also elsewhere on the board
26: R33.2, SW1.2, SW1.3, U1.26 (RUN); also elsewhere on the board
26G: U1.38 (GPIO26_ADC0)
27: U1.39 (GPIO27_ADC1)
28: U1.40 (GPIO28_ADC2)
29: U1.41 (GPIO29_ADC3)
+1V1: C3.1, C4.1, C5.1, U1.23 (DVDD), U1.45 (VREG_VOUT), U1.50 (DVDD)
GND: C1.1, C2.1, C3.2, C4.2, C5.2, C6.2, C7.2, C8.2, C9.2, C10.2, C11.2, C12.2, C13.2, C14.2, C15.2, C16.2, C17.2, D2.3 (VSS), D3.3 (common), D4.1 (K), D5.1 (K), J1.A1 (GND), J1.A12 (GND), J1.B1 (GND), J1.B12 (GND), J1.S1 (SHIELD), J2.1, J2.S1 (SHIELD), J2.S2 (SHIELD), J8.2, J9.2, JP4.1 (A), R2.2, R3.2, S1.MP1, S1.MP2, S1.MP3, S1.MP4, SW1.1, SW1.4, SW2.2, SW2.3, U1.19 (TESTEN), U1.57 (GND), U3.1 (GND), U4.1 (GND), U5.4 (GND), U5.9 (EP), Y1.2, Y1.4; also elsewhere on the board
H: JP3.3 (B), JP4.2 (B)
unnamed: C2.2, R16.1, Y1.1
unnamed: D1.2 (A), J1.A4 (VBUS), J1.A9 (VBUS), J1.B4 (VBUS), J1.B9 (VBUS)
unnamed: C13.1, D1.1 (K), S1.1
unnamed: D2.1 (VDD), J10.1
unnamed: D4.2 (A), R8.1
unnamed: D5.2 (A), R1.2
unnamed: J1.A5 (CC1), R2.1
unnamed: J1.B5 (CC2), R3.1
unnamed: J8.1, U1.24 (SWCLK)
unnamed: J8.3, U1.25 (SWD)
unnamed: J9.1, S1.3
unnamed: JP1.1 (A), R17.2
unnamed: JP2.1 (A), R15.2
unnamed: R6.1, SW2.1, SW2.4
unnamed: C1.2, U1.20 (XIN), Y1.3
unnamed: R16.2, U1.21 (XOUT)
QSPI_SCLK: U1.52 (QSPI_SCLK), U5.6 (CLK)
QSPI_SD0: U1.53 (QSPI_SD0), U5.5 (DI(IO0))
QSPI_SD2: U1.54 (QSPI_SD2), U5.3 (IO2)
QSPI_SD3: U1.51 (QSPI_SD3), U5.7 (IO3)
QSPI_SS: R6.2, R7.2, U1.56 (QSPI_SS), U5.1 (~CS)
QSPI_SSD1: U1.55 (QSPI_SD1), U5.2 (DO(IO1))
RX: SW3.1 (A), SW3.6 (C), U1.3 (GPIO1)
TX: SW3.3 (C), SW3.4 (A), U1.2 (GPIO0)
USBD_N: D3.1 (A1), J1.A7 (D-), J1.B7 (D-), R4.1
USBD_P: D3.2 (A2), J1.A6 (D+), J1.B6 (D+), R5.1
USB_DN: R4.2, U1.46 (USB_DM)
USB_DP: R5.2, U1.47 (USB_DP)
VBUS: F1.2, U3.3 (VI), U4.3 (VI)
VIN: C16.1, F1.1, S1.2; also elsewhere on the board

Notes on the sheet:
NEOPIXEL
RP2040 MCU
SPARKFUN QWIIC
STABILITY CAPS
RESET SW
DEBUG
STORAGE WINBOND CHIP
QWIIC PULL-UP
BLINKEN LIGHTS
USB-C & POWER

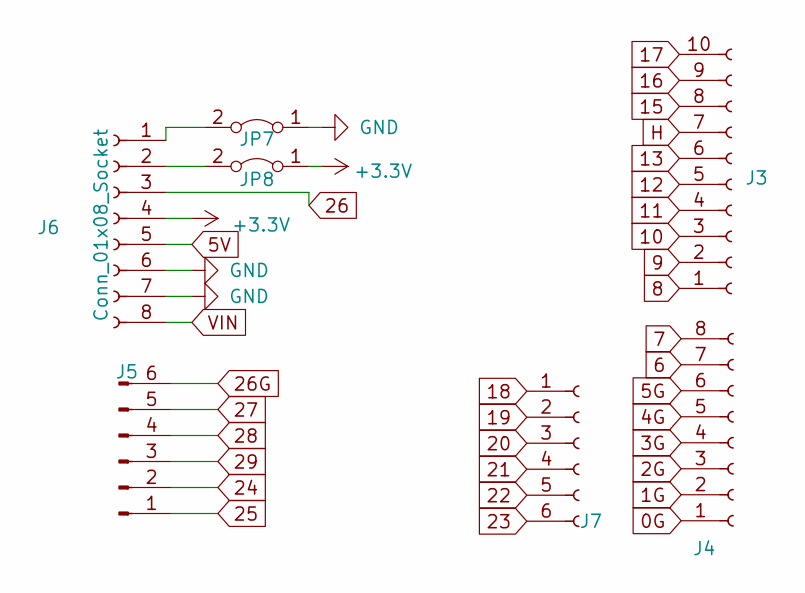
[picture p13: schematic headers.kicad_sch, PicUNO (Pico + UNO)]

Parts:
J3: Conn_01x10_Socket; PinSocket_1x10_P2.54mm_Vertical
J4, J6: Conn_01x08_Socket; PinSocket_1x08_P2.54mm_Vertical
J5: Conn_01x06_Pin; PinSocket_1x06_P2.54mm_Vertical
J7: Conn_01x06_Socket; PinSocket_1x06_P2.54mm_Vertical
JP7, JP8: Jumper_2_Bridged; SolderJumper-2_P1.3mm_Open_RoundedPad1.0x1.5mm

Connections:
3V: J6.4, JP8.1 (A); also elsewhere on the board
5V: J6.5; also elsewhere on the board
17: J3.10; also elsewhere on the board
20: J7.3; also elsewhere on the board
21: J7.4; also elsewhere on the board
24: J5.2; also elsewhere on the board
25: J5.1; also elsewhere on the board
26: J6.3; also elsewhere on the board
GND: J6.6, J6.7, JP7.1 (A); also elsewhere on the board
unnamed 69: J6.1, JP7.2 (B); also elsewhere on the board
unnamed 70: J6.2, JP8.2 (B); also elsewhere on the board
VIN: J6.8; also elsewhere on the board

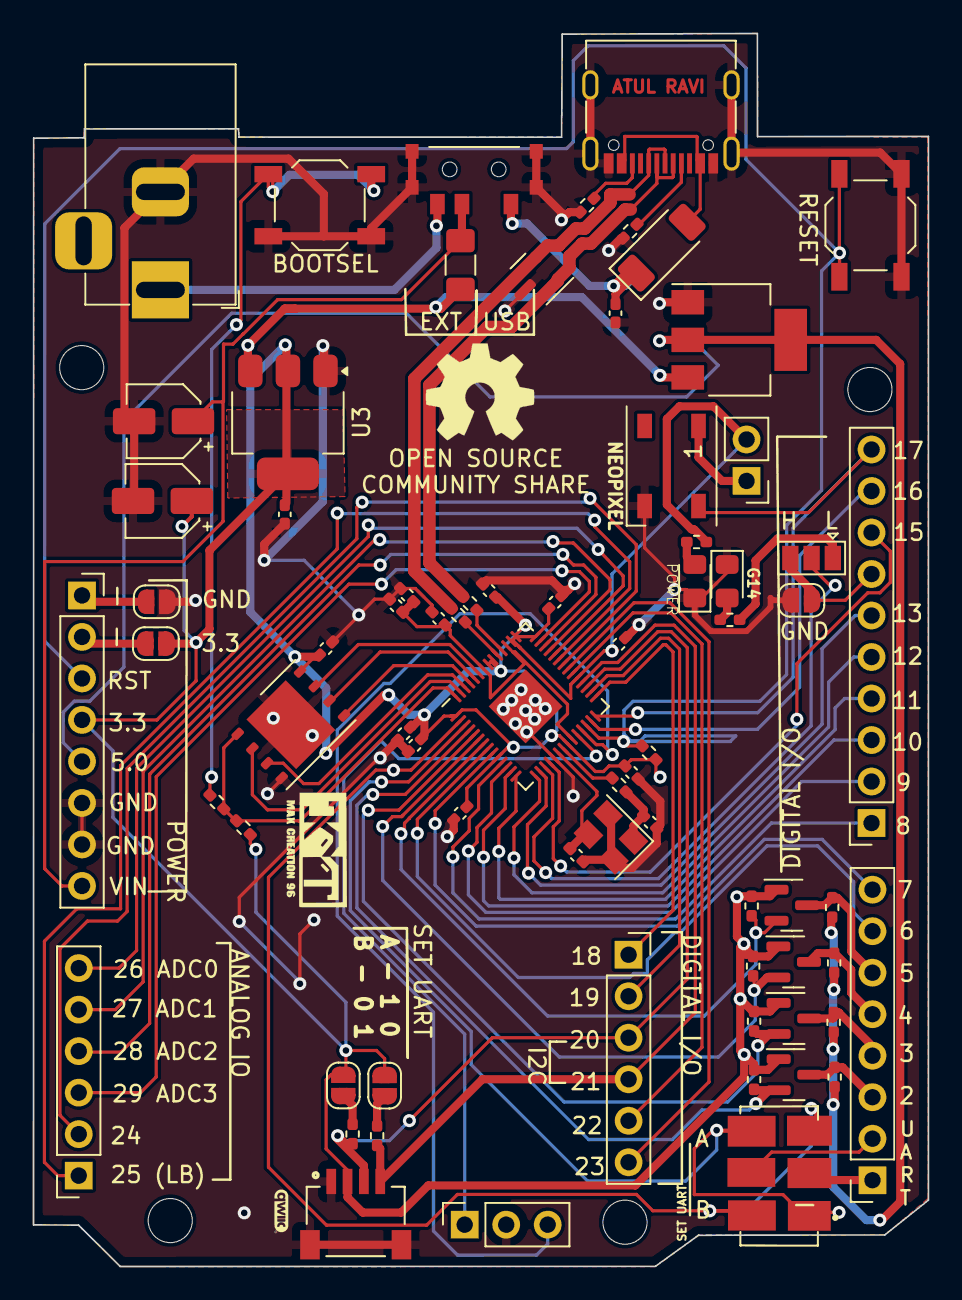
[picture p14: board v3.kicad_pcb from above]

Board: 2 copper layers, 54.8 x 75.5 mm, 75 parts (0 on the bottom side), 54 nets.

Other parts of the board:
JP5, JP6: Jumper_2_Bridged; SolderJumper-2_P1.3mm_Open_RoundedPad1.0x1.5mm
REF1**, REF2**, REF3**: MountingHole_2.7mm_M2.5_ISO14580

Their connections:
3V: JP5.1 (A); also elsewhere on the board
GND: JP6.1 (A); also elsewhere on the board
unnamed 69: JP6.2 (B); also elsewhere on the board
unnamed 70: JP5.2 (B); also elsewhere on the board

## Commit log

2025-06-26 3D View of the PCB is uploaded as Image
2025-06-26 Added bare minimum Arduino-board configuration
2025-06-26 Kicad files are uploaded
    [ARDUNIO_ADV.kicad_pcb, ARDUNIO_ADV.kicad_sch]
2025-06-26 Drill files are Uploaded !!
    [ARDUNIO_ADV-NPTH.drl, ARDUNIO_ADV-PTH.drl]
2025-06-26 Gerber files are uploaded for Fabrication
    Read the Readme.md before using the Gerber files !!
    [ARDUNIO_ADV-B_Cu.gbr, ARDUNIO_ADV-B_Mask.gbr, ARDUNIO_ADV-B_Paste.gbr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]
2025-08-07 Pheripherals shematics added
    [pheripherals.kicad_sch]
